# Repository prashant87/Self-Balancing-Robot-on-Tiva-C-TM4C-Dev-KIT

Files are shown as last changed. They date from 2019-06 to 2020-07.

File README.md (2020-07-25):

# Self-Balancing-Robot-on-Tiva-C-TM4C-Dev-KIT

Main of implementation:
- Kalman filter and Complementary filter for accelerometer and gyroscope on MPU6050 6axis.
- PID Controller for two values: the Robot angle and the Robot Velocity.
- RF, Bluetooth transmition for Control purpose.
- Hardwave driver, booster pack for Tiva C KIT

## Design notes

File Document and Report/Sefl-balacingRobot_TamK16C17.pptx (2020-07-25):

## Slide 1

Self-Balancing Robot
Tam Nguyen-Thanh

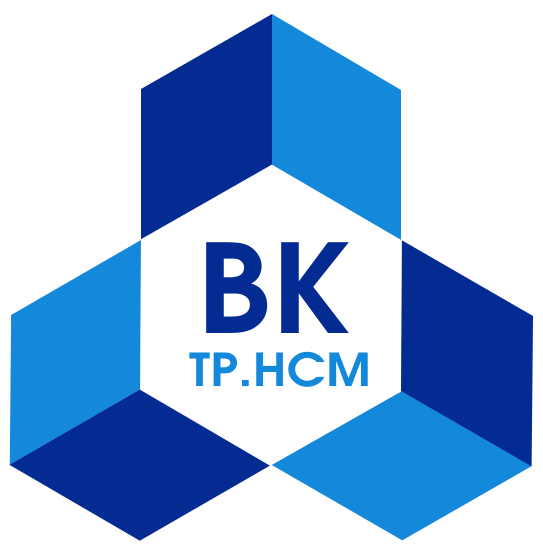
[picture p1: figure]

INTRODUCTION
This paper presents a two-wheel self-balancing robot based on Tiva C TM4C123G using Kalman filter to estimate angle from accelerometer and gyroscope. PID algorithm to control angle, position and velocity.

SYSTEM OVERVIEW
TM4C123G is Cortex-M4 32bit based on ARM architecture including Tiva C launchpad as MCU of the system. Thanks to TivaWare, programming for MCU is made easier.

HARDWARE DESIGN

- Mechanical: Robots are designed to have its center as low as possible and divided into layers to protect electronic components. The frame should be compact and hard using SolidWork to design.

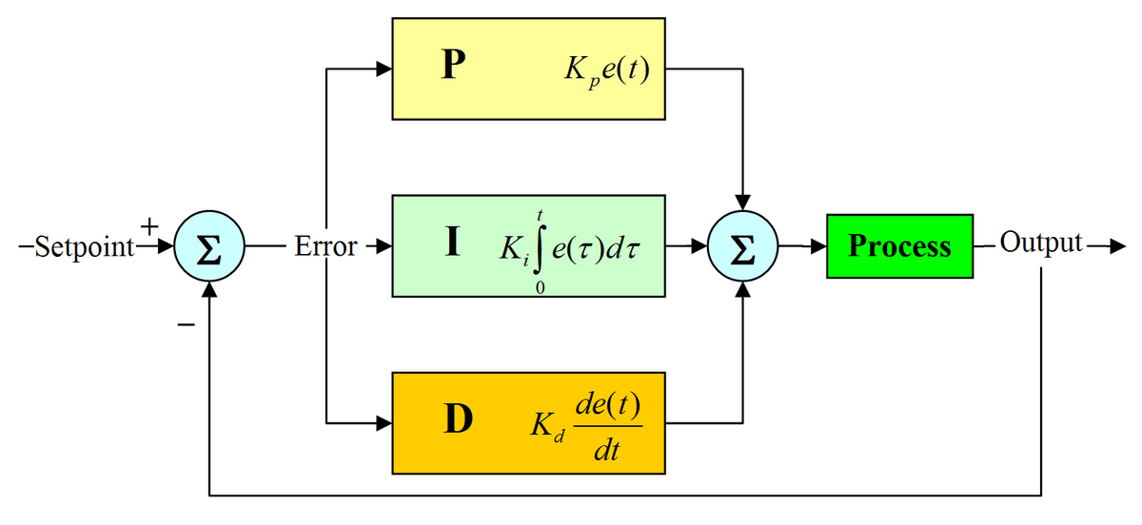
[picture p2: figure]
Káº¿t quáº£ hÃ¬nh áº£nh cho pid control

Fig. 6. The block diagram of PID controller

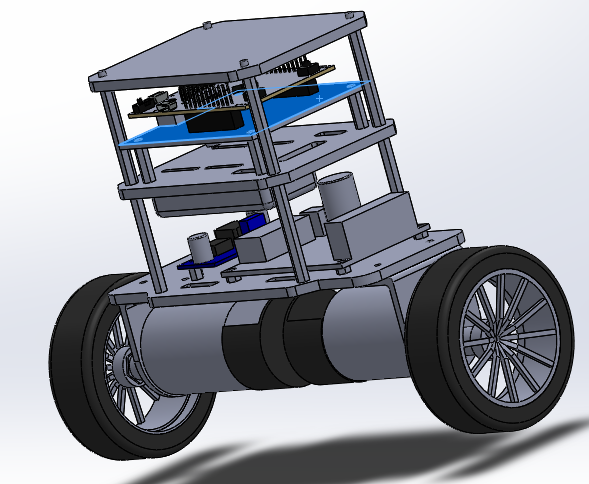
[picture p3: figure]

Figure 4. 3D view of the robot on SolidWork 2018

- Mainboard: where the Tiva C Launchpad, MPU 6050 and other electronic parts are located.

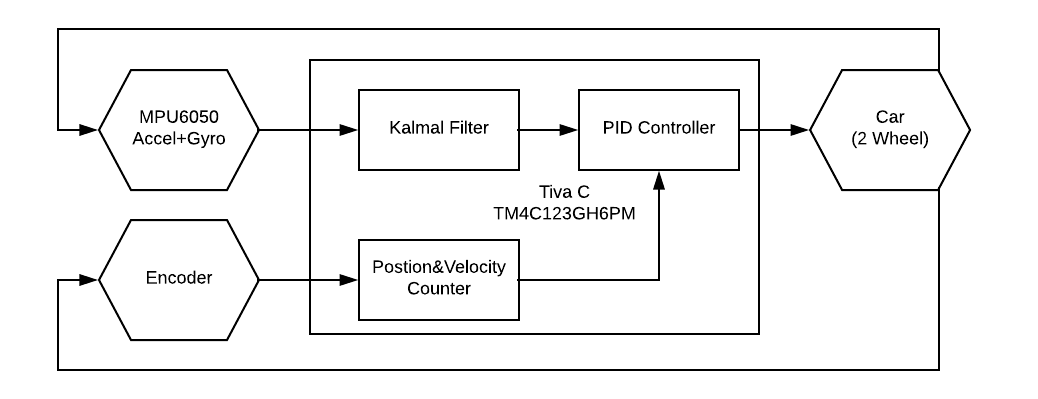
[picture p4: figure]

Figure 7. System block diagram.

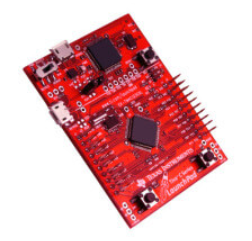
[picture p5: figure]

Figure 1. Tiva C Launchpad.

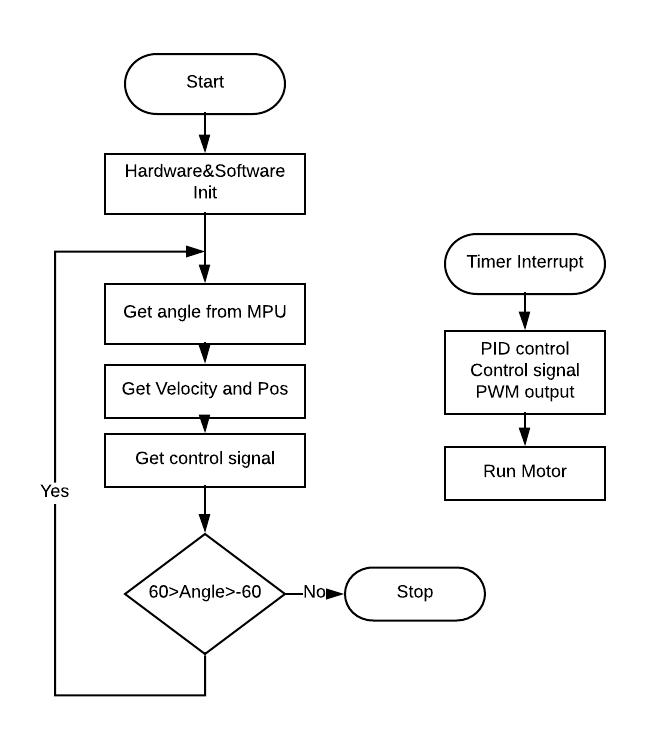
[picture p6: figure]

Figure 7. Flow algorithm

The MPU-6050 is integrated with 6-axis
MotionTracking device that combines a 3
axis gyroscope, 3-axis accelerometer, and
DMP all in a small 4x4x0.9mm package.
The angle is calculated from the parameters
taken from the sensor.

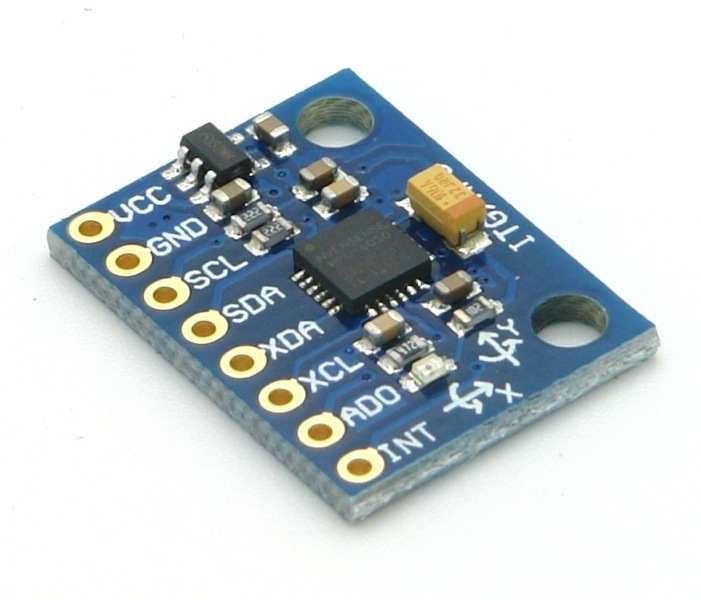
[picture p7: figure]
Káº¿t quáº£ hÃ¬nh áº£nh cho mou 6050

Figure. 2. MPU 6050.

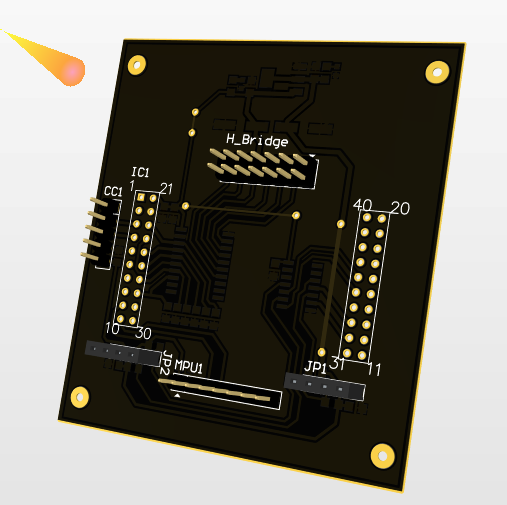
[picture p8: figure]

Figure 5. 3D view mainboard
on Altium 18

CONTROL SYSTEM
A proportional–integral–derivative controller (PID controller or three-term controller) is a control loop feedback mechanism widely used in industrial control systems and a variety of other applications requiring continuously modulated control. A PID controller continuously calculates an error value e(t) as the difference between a desired setpoint (SP) and a measured process variable (PV) and applies a correction based on proportional, integral, and derivative terms.

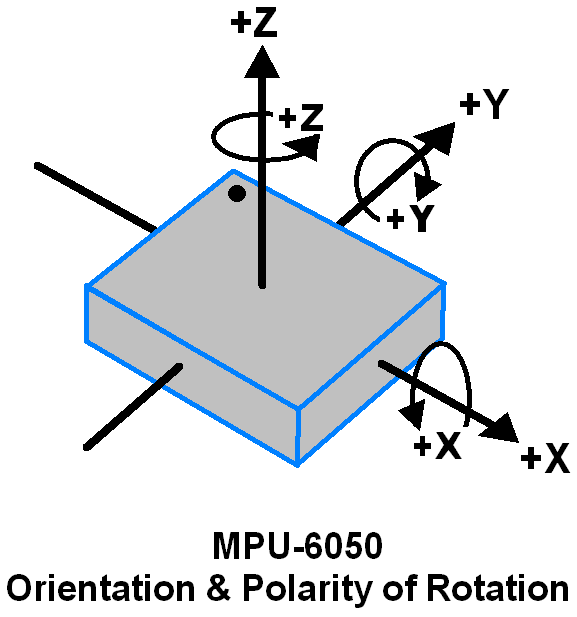
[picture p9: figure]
Káº¿t quáº£ hÃ¬nh áº£nh cho mou 6050

RESULTS AND CONCLUSION

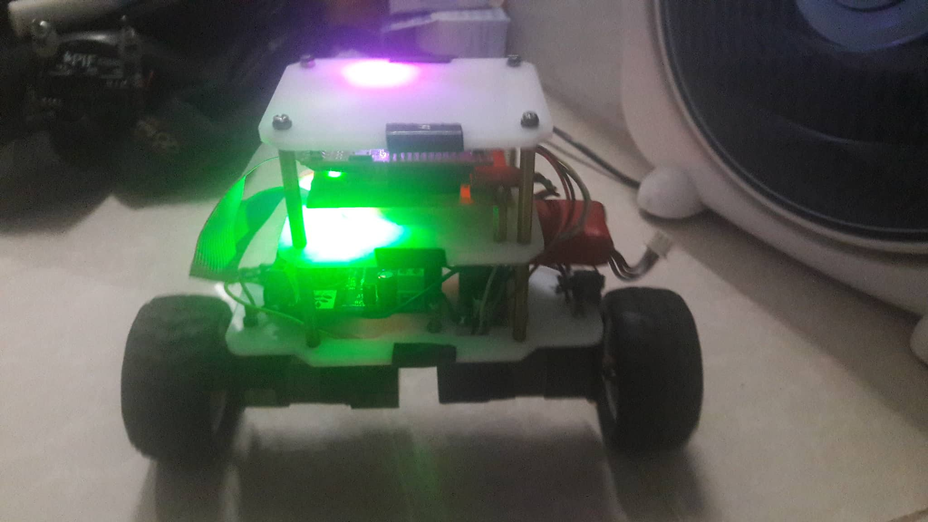
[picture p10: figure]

Figure 9. Photo of the complete robot

The robot can stand up firmly and stably after calibrating system parameters and its speed and location can be controlled wirelessly.
Development direction: use LQR in replacement of out-dated and flawed PID.

For driving motors, DRV8412 Dual Full-Bridge PWM Motor Driver is used. Driver have PWM Operating Frequency up to 500 kH. H-Bridge MOSFETs and an intelligent gate drive design, so the efficiency of
these motor drivers can be up to 97%.

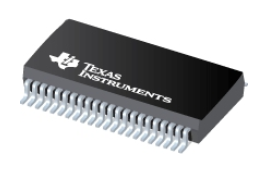
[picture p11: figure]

Figure. 3. DRV 84x2

The 2019 PIF 9th Anniversary. January 4th, 2019, Ho Chi Minh City.

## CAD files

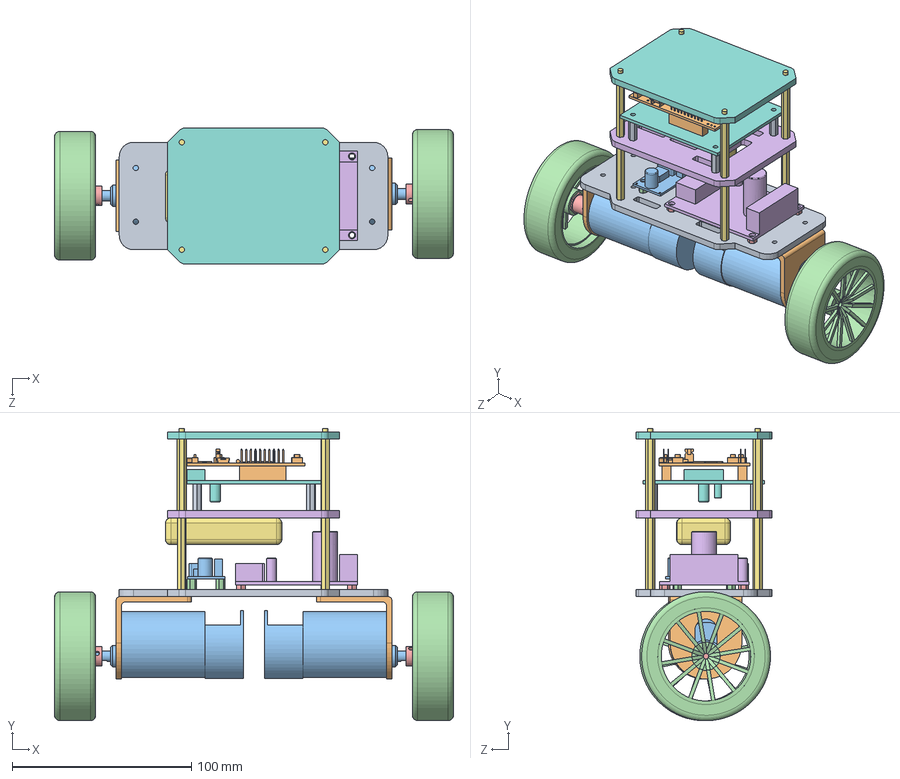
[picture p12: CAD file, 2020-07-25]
Mechanical/Robot Frame Base/Assembly.SLDASM
222.8 x 163.2 x 76.0 mm
Base1
Gá động cơ x 2
Động cơ x 2
Bánh xe x 2
Nối trục ĐC x 2
Cầu H
Pin2s
Mạch TT
Trụ15 x 4
TivaC
MạchBoost
Trụ6 x 2
Truj2.5 x 4
Base2
Trụ40 x 8
Base3

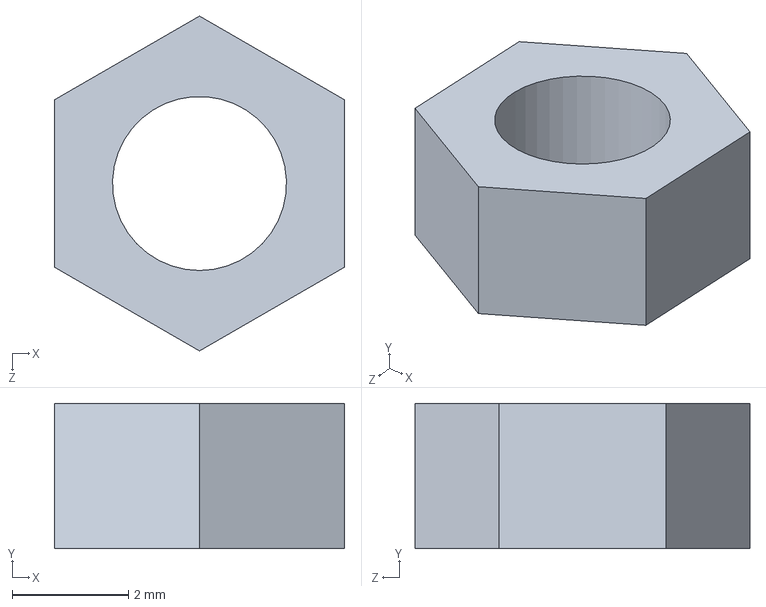
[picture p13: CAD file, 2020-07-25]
Mechanical/Robot Frame Base/Truj2.5.SLDPRT
5.00 x 2.50 x 5.77 mm

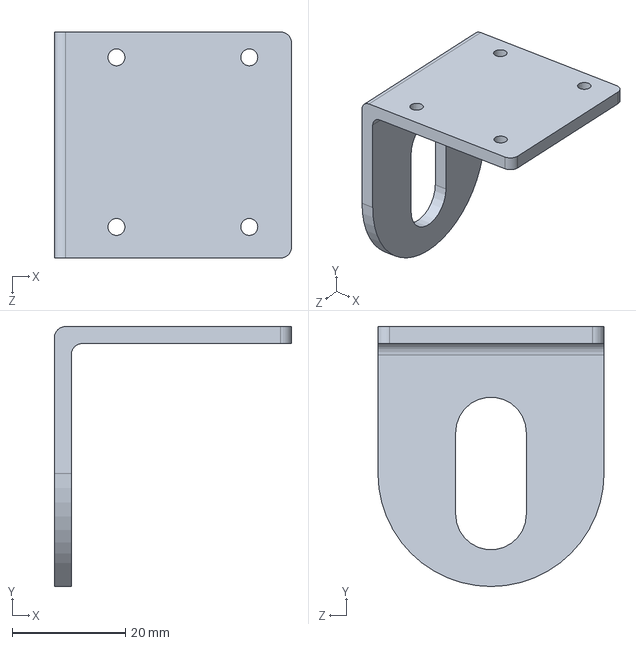
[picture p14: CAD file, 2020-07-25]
Mechanical/Robot Frame Base/Gá động cơ.SLDPRT
42.0 x 46.0 x 40.0 mm

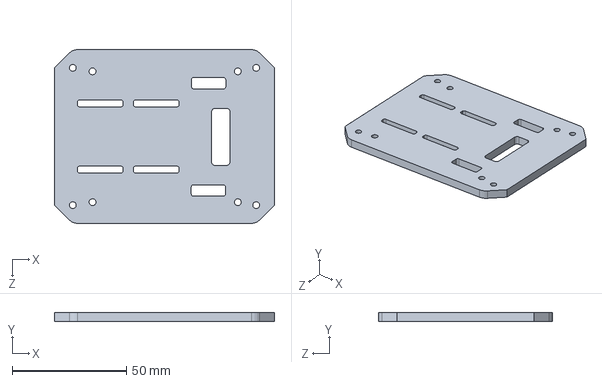
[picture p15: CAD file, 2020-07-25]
Mechanical/Robot Frame Base/Base2.SLDPRT
96.1 x 4.00 x 76.0 mm

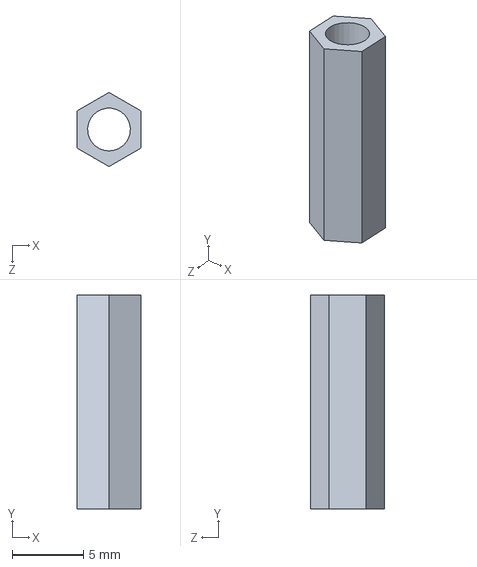
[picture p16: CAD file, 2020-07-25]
Mechanical/Robot Frame Base/Trụ15.SLDPRT
4.50 x 15.0 x 5.20 mm

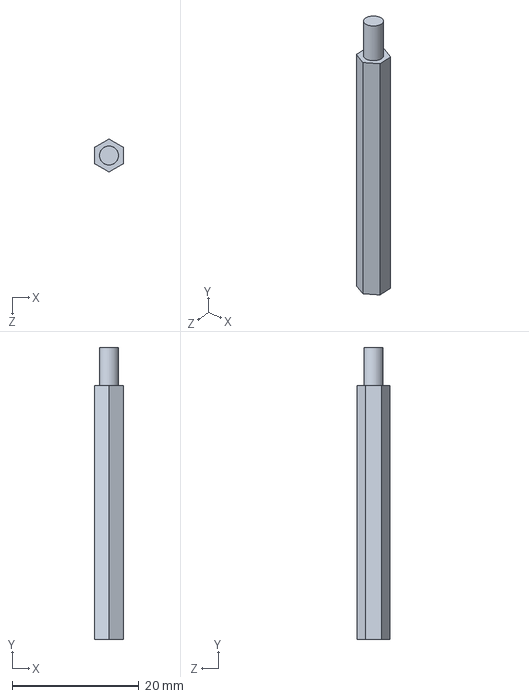
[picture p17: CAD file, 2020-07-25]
Mechanical/Robot Frame Base/Trụ40.SLDPRT
4.50 x 46.0 x 5.20 mm

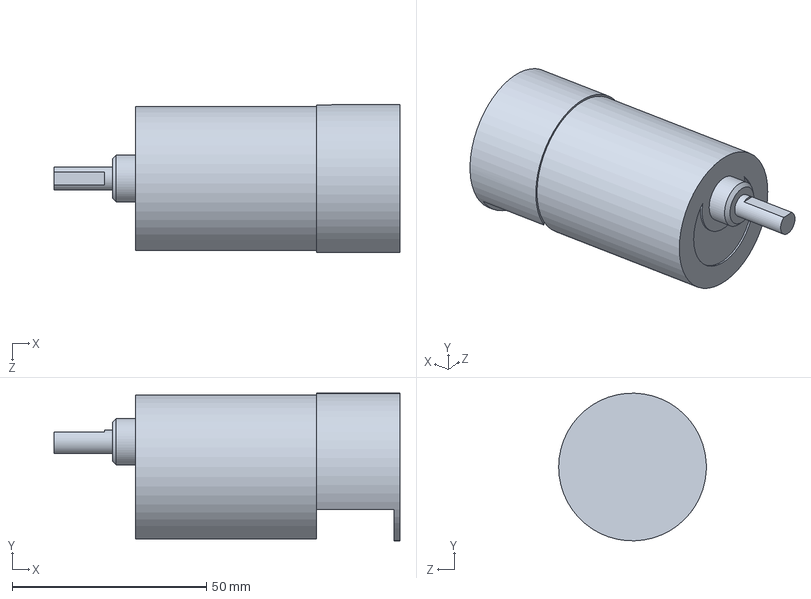
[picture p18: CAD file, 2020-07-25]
Mechanical/Robot Frame Base/Động cơ.SLDPRT
89.0 x 38.0 x 38.0 mm

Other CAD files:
Firmware/Tiva C with RTOS/Debug/Application/freertos_demo.obj
Firmware/Tiva C with RTOS/Debug/Application/motor_control/motor_control.obj
Firmware/Tiva C with RTOS/Debug/Application/pid/pid.obj
Firmware/Tiva C with RTOS/Debug/Application/TwoWheel/twowheel.obj
Firmware/Tiva C with RTOS/Debug/drivers/MPU6050.obj
Firmware/Tiva C with RTOS/Debug/drivers/uartstdio.obj
Firmware/Tiva C with RTOS/Debug/drivers/pwm.obj
Firmware/Tiva C with RTOS/Debug/drivers/switches.obj
Firmware/Tiva C with RTOS/Debug/drivers/led.obj
Firmware/Tiva C with RTOS/Debug/drivers/qei.obj
Firmware/Tiva C with RTOS/Debug/drivers/buttons.obj
Mechanical/Robot Frame Base/Base1.SLDPRT
Mechanical/Robot Frame Base/Base3.SLDPRT
Mechanical/Robot Frame Base/Base4.SLDPRT
Mechanical/Robot Frame Base/Bánh xe.SLDPRT
Mechanical/Robot Frame Base/Cầu H.SLDPRT
Mechanical/Robot Frame Base/IMU_Quick.SLDPRT
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

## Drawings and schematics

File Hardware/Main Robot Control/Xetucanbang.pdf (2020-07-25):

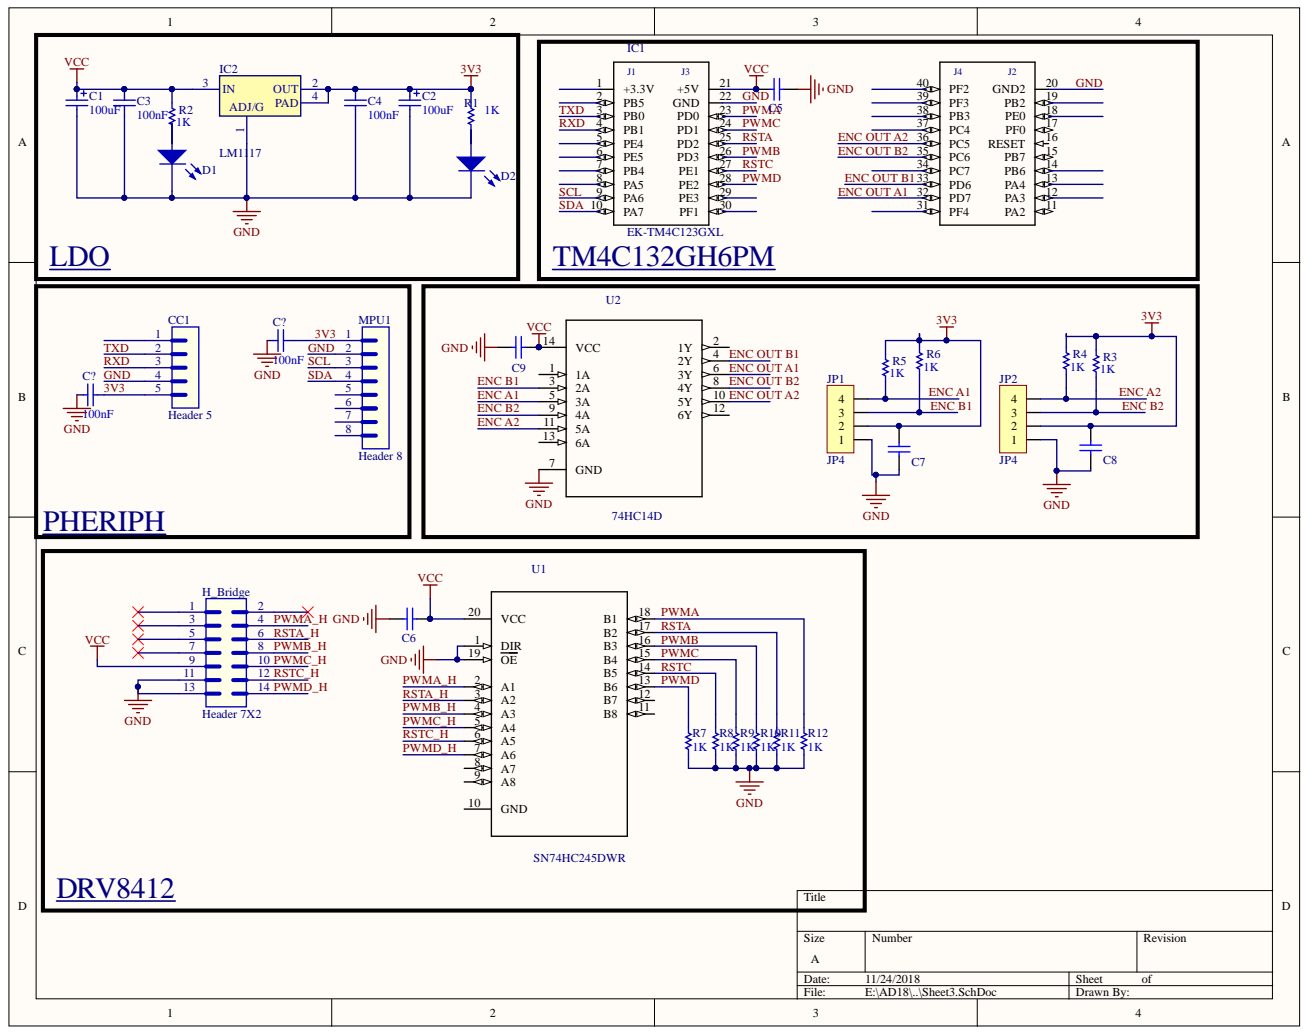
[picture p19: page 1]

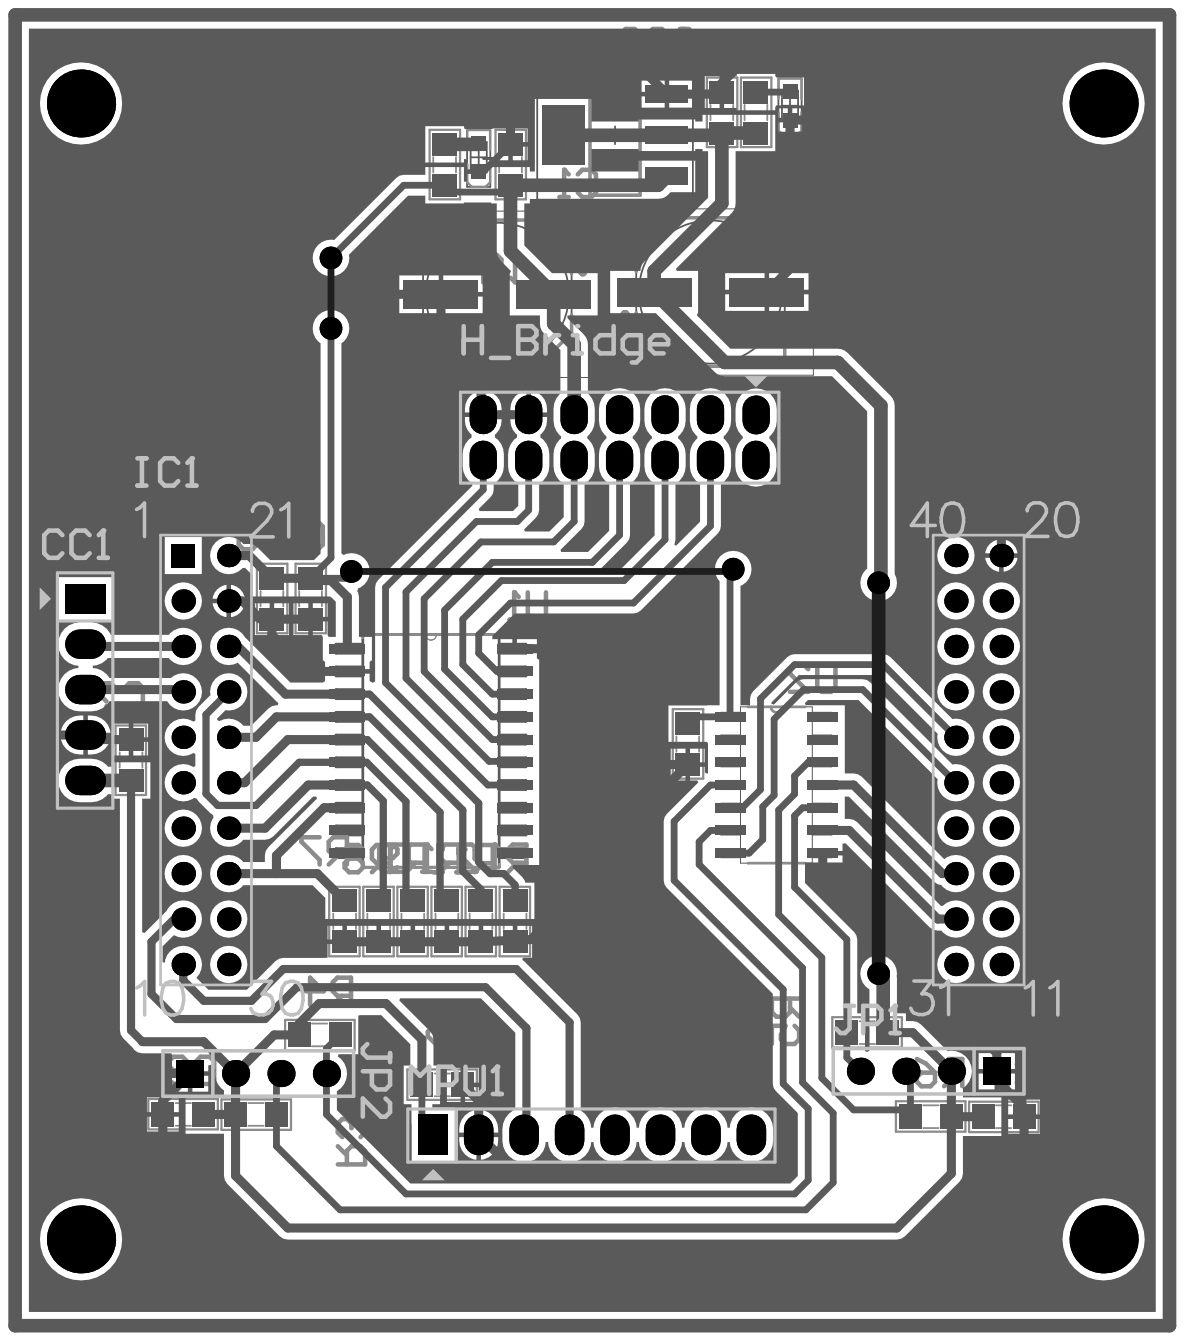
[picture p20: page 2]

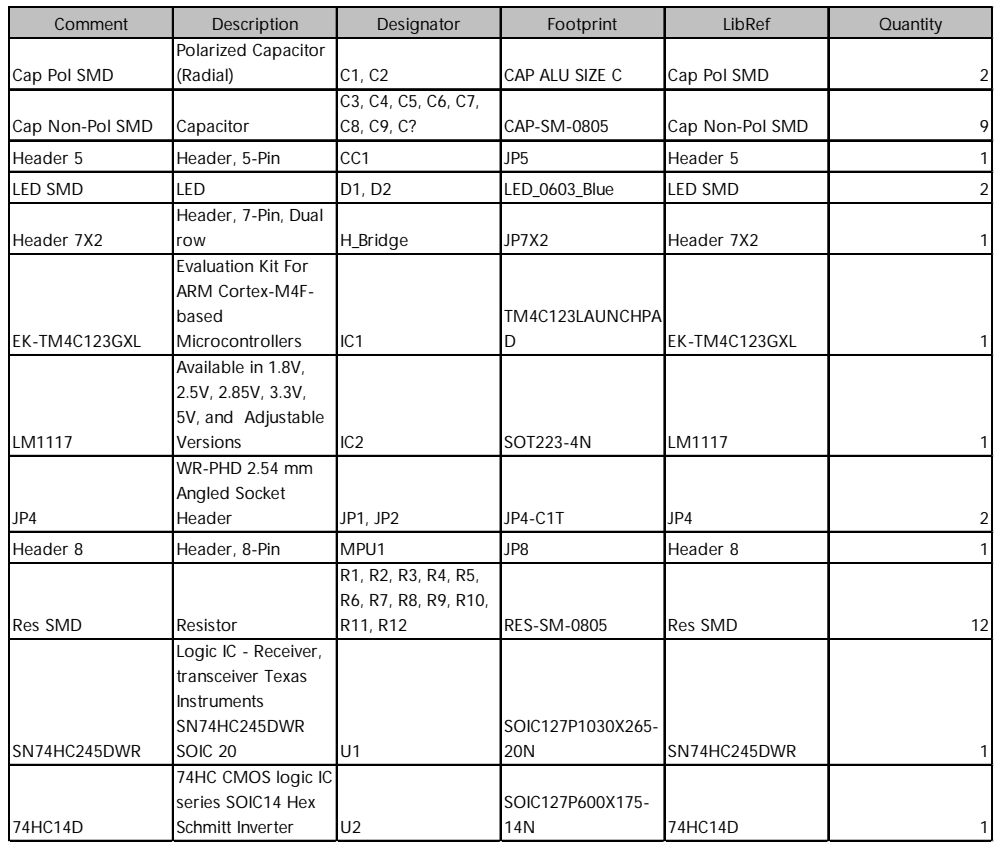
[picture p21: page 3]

Comment | Description | Designator | Footprint | LibRef | Quantity
Cap Pol SMD | Polarized Capacitor (Radial) | C1, C2 | CAP ALU SIZE C | Cap Pol SMD | 2

Cap Non-Pol SMD | Capacitor | C3, C4, C5, C6, C7, C8, C9, C? | CAP-SM-0805 | Cap Non-Pol SMD | 9

Header 5 | Header, 5-Pin | CC1 | JP5 | Header 5 | 1

LED SMD | LED | D1, D2 | LED_0603_Blue | LED SMD | 2
Header 7X2 | Header, 7-Pin, Dual row | H_Bridge | JP7X2 | Header 7X2 | 1

EK-TM4C123GXL | Evaluation Kit For ARM Cortex-M4F-based Microcontrollers | IC1 | TM4C123LAUNCHPA D | EK-TM4C123GXL | 1

LM1117 | Available in 1.8V, 2.5V, 2.85V, 3.3V, 5V, and Adjustable Versions | IC2 | SOT223-4N | LM1117 | 1

JP4 | WR-PHD 2.54 mm Angled Socket Header | JP1, JP2 | JP4-C1T | JP4 | 2

Header 8 | Header, 8-Pin | MPU1 | JP8 | Header 8 | 1
Res SMD | Resistor | R1, R2, R3, R4, R5, R6, R7, R8, R9, R10, R11, R12 | RES-SM-0805 | Res SMD | 12

SN74HC245DWR | Logic IC - Receiver, transceiver Texas Instruments SN74HC245DWR SOIC 20 | U1 | SOIC127P1030X265-20N | SN74HC245DWR | 1

74HC14D | 74HC CMOS logic IC series SOIC14 Hex Schmitt Inverter | U2 | SOIC127P600X175-14N | 74HC14D | 1

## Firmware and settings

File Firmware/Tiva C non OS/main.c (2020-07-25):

#include "include.h"

//

int data[10];

void main(void)


{

    SysCtlClockSet(SYSCTL_SYSDIV_2_5|  SYSCTL_USE_PLL | SYSCTL_OSC_MAIN | SYSCTL_XTAL_16MHZ) ;
    PWM_Init();
    CC1101_Init();
    SW_Init();
    Timer_Init();
    MPU6050_Init();
    IntMasterEnable();
    QEIL_Init();
    QEIR_Init();
    State_Banlance=5;
    V_left_set=00;
    V_right_set=00;
    PWM_Enable(1,1);
//    double i=3.14;
     while (1)
     {
//        PWM_Run(30,50);
//        Kalman_Filter_Process();
//        MPU6050_Complimentary_Angle(MPU6050_DegGet);
//         MPU6050_Kalman_Angle(MPU6050_DegGet);
        V_left=-QEIVeloGet_left();
        V_right=-QEIVeloGet_right();
        LED_Status();
//        UART_Control();

//4

//        sprintf((char*)data, "%d  \n",(int)(100*ahrs_get_yaw()));
        UART_C1101_Write(data,strlen((char*)data));
        SysCtlDelay(SysCtlClockGet()/30);
    }

}

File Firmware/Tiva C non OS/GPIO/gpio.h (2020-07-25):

#ifndef gpio_h_
#define gpio_h_

#define LEDBLUE GPIO_PIN_2
#define LEDRED GPIO_PIN_1
#define LEDGREEN GPIO_PIN_3
#define PORTF GPIO_PORTF_BASE
#define SW1 GPIO_PIN_4

#define SW2 GPIO_PIN_0
extern void LED_Status(void);
extern void SW_Init(void);
extern void SW_Isr(void);
extern unsigned char SW_Status(void);
#endif

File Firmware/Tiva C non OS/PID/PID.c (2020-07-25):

#include "PID.h"
#include "../include.h"
double PWM_SetD;

extern void PID_Deg(double Deg_Status)
{

      static double error;
      error=State_Banlance-Deg_Status;
      PWM_SetD= PID_Deg_Process(error);
//      if(PWM_SetD<pwm_low)
//          PWM_SetD=pwm_low;
//      if(PWM_SetD>pwm_high)
//          PWM_SetD=pwm_high;
      PWM_Deg=PWM_SetD;
//          PWM=PWM_Set;
  // return PWM_Set;
}

double PID_Deg_Process(double error)
{
        e__ = e_;
        e_ = e;
        e = error;
        u_ = u;
        u = u_ + Kp * (e - e_)
               + Ki * Ts * (e + e_)
               + (Kd / Ts) * (e - (2 * e_) + e__);
        return (u/pwm_div);
}
double PID_Error_Deg(double Deg_Status)
{
        return State_Banlance-Deg_Status;
}
extern void PID_Velo_Left(void)
{
    static double V_Erorr_Left;
    V_Erorr_Left=V_left_set-V_left;
    PWM_SetV_Left=PID_Velo_Left_Process(V_Erorr_Left);
}

double PID_Velo_Left_Process(double error)
{
       evl__ = evl_;
       evl_ = evl;
       evl = error;
       uvl_ = uvl;
       uvl = uvl_ + Kpv * (evl - evl_)
               + Kiv * T * (evl + evl_)
               + (Kdv / T) * (evl - (2 * evl_) + evl__);
        return (uvl/pwm_velo_div);
}
extern void PID_Velo_Right(void)
{
    static double V_Erorr_Right;
    V_Erorr_Right=V_right_set-V_right;
    PWM_SetV_Right=PID_Velo_Right_Process(V_Erorr_Right);
}

double PID_Velo_Right_Process(double error)
{
       evr__ = evr_;
       evr_ = evr;
       evr = error;
       uvr_ = uvr;
       uvr = uvr_ + Kpr * (evr - evr_)
               + Kir * T * (evr + evr_)
               + (Kdr / T) * (evr - (2 * evr_) + evr__);
        return (uvr/pwm_velo_div);
}

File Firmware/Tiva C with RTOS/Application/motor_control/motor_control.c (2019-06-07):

#include "motor_control.h"

#include "debug.h"
#include "drivers/pwm.h"
#include "drivers/qei.h"
#include "pid/pid.h"

#include "driverlib/sysctl.h"

#include "FreeRTOS.h"
#include "timers.h"
//#include "os_task.h"
//#include "os_timer.h"

pid_controller_t  PID_Velocity[2];


static float w_get[2];
static float w_set[2];
static float w_run[2];
static TimerHandle_t xTimersMoveBase;


void motor_control_service_loop(TimerHandle_t xTimer);


xStatusTypeDef   motor_control_serivce_init(void)
{
    PWM_Init();
    HBrigdeEnable(LEFT, OFF);
    HBrigdeEnable(RIGHT, OFF);
    QEI_Init();



    PID_Velocity[LEFT]=(pid_controller_t)
               {
                   .kp=0.07,
                   .ki=00.0004,
                   .kd=0.001,//0.006
                   .i_part_max = 100,
                      .i_part_min = -80,
                      .output_max = 80,
                      .output_min = -100,
                      .ouput_offset = 0
               };
    PID_Velocity[RIGHT]=(pid_controller_t)
               {

                .kp=0.07,
                .ki=00.0004,
                .kd=0.001,//0.006
                .i_part_max = 100,
                   .i_part_min = -80,
                   .output_max = 80,
                      .output_min = -100,
                      .ouput_offset = 0
               };

    pid_init(&PID_Velocity[LEFT]);
    pid_init(&PID_Velocity[RIGHT]);

    xTimersMoveBase = xTimerCreate("Move base", MOVEBASE_PERIOD_MS, pdTRUE, ( void * ) 0, motor_control_service_loop);
//    xTimersMoveBase = xTimerCreate("Move base", MOVEBASE_PERIOD_MS, pdTRUE, ( void * ) 0, motor_control_service_loop);

    SysCtlDelay(100);


    return OK;
}
xStatusTypeDef motor_control_service_start(void)
{
    xTimerStart( xTimersMoveBase, 0 );
    return OK;
}
void motor_control_service_loop(TimerHandle_t xTimer)
{
    w_get[LEFT]=-QEI_Get(LEFT);
    w_get[RIGHT]=-QEI_Get(RIGHT);

    w_run[LEFT]=pid_compute(&PID_Velocity[LEFT], w_set[LEFT] - w_get[LEFT],MOVEBASE_PERIOD_MS );
    w_run[RIGHT]=pid_compute(&PID_Velocity[RIGHT], w_set[RIGHT] - w_get[RIGHT],MOVEBASE_PERIOD_MS );

    motor_set_speed(LEFT, w_run[LEFT]);
    motor_set_speed(RIGHT, w_run[RIGHT]);

   // DBG("DBG1: %d DBG2: %d %d \n ",(int)w_get[LEFT],(int)w_set[LEFT],(int)w_get[RIGHT]);
//    DBG("DBG2: %d\n ",(int)w_set[LEFT]);
//    DBG("DBG: En:%d  \n ",(int)w_get[RIGHT]);
//    DBG("DBG: PWM_OUT_1: %d \n ",(int)w_run[LEFT]);
//    DBG("DBG: PWM_OUT_2: %d  \n ",(int)w_run[RIGHT]);
}

xStatusTypeDef motor_set(float w[2])
{
    w_set[LEFT]=w[LEFT];
    w_set[RIGHT]=w[RIGHT];
    return OK;
}

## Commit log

2019-06-08 Add another pid lib to adapt seft-balancing model
    [MPU6050.obj, motor_control.obj, pid.obj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]
2020-07-25 Add file and create folder structure
    [Assembly.SLDASM, Base1.SLDPRT, Base2.SLDPRT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]
